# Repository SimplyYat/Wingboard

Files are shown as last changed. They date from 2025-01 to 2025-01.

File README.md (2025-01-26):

# Wingboard

> [!IMPORTANT]
> This is a work in progress.

A unibody ergonomic keyboard developed using [Ergogen](https://github.com/ergogen/ergogen) based on the [Absolem keyboard design](https://zealot.hu/absolem/).

## Row Column Matrix
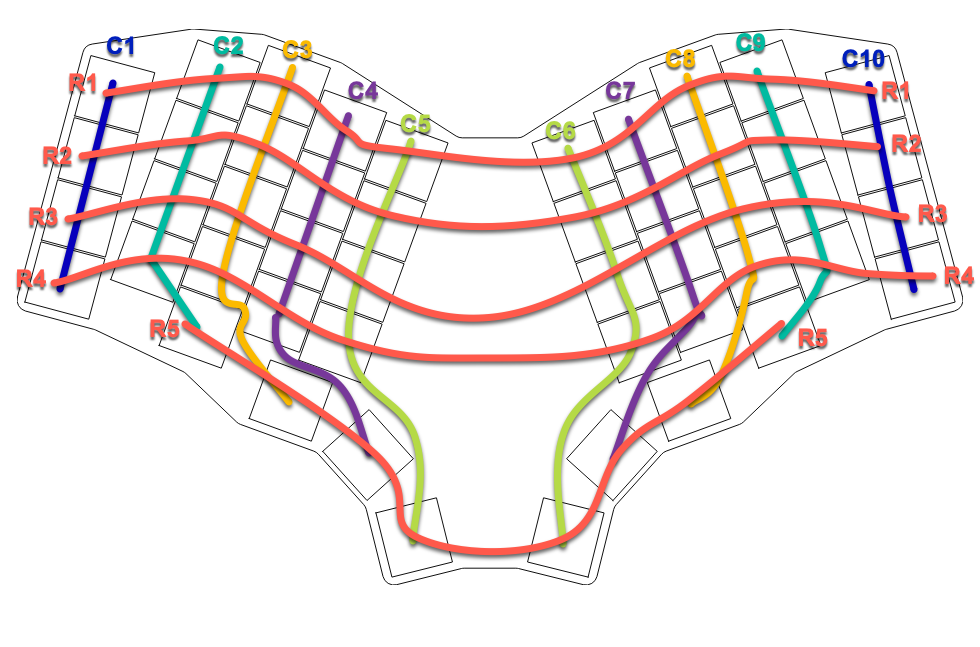
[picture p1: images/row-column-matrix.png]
Rows and Columns matrix


## Components needed

Component | Type (THT, SMD, or No Solder) | Link | Quantity | LCSC Part Number (for SMT Assembly through JLCPCB)
---------|---------|----------|---------|---------
 Diode SOD-123/323 (1N4148/W) | SMD | [AliExpress](https://www.aliexpress.com/item/1005003194674618.html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) | 48 | [C81598](https://jlcpcb.com/partdetail/st_semtech-1N4148W/C81598)
 Kailh Low Profile Hot Swap Switches | SMD | [AliExpress](https://www.aliexpress.com/item/1005003575767699.html?spm=a2g0o.detail.0.0.52b8WBreWBreoo&mp=1) | 48 | [C5333465](https://jlcpcb.com/partdetail/Kailh-CPG135001S30/C5333465)
 Choc V2 Key Switches | No Solder | [Deep Sea Silent Switches](https://www.aliexpress.com/item/1005008113631450.html?spm=a2g0o.detail.0.0.52b8WBreWBreoo&mp=1), [Choose from here](https://www.aliexpress.com/item/1005006626760418.html?spm=a2g0o.detail.0.0.52b8WBreWBreoo&mp=1), or find your own | 48 | Manual install
 Choc V2 Key Caps | No Solder | 48 | Manual install
 Supermini NRF52840 MCU | THT | [AliExpress](https://www.aliexpress.com/item/1005001621678794.html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) | 1 | Manual install
 Nice!View Display | THT | [Nice!View](https://nicekeyboards.com/nice-view) | 1 | Manual install
 EC11/12 Rotary Encoder | THT | [AliExpress](https://www.aliexpress.com/item/1005007644083514.html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) | 1 | Manual install
 Knob for the rotary encoder shaft | No Solder | [AliExpress](https://www.aliexpress.com/item/1005004171280417.html?spm=a2g0o.detail.0.0.52b8WBreWBreoo&mp=1) | 1 | Manual install
 Side Push Reset Switch (EVQPUC02K) | SMD | [AliExpress](https://www.aliexpress.com/item/1005002845025014.html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) | 1 | [C79174](https://jlcpcb.com/partdetail/Panasonic-EVQPUC02K/C79174)
 Power Switch | SMD | TBD | 1 | Manual install
 JST PH 2.0mm 2-Pin Connector for Battery | SMD | [AliExpress (Horizontal ones)](https://www.aliexpress.com/item/1005005716487667.html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) | 1 | [C7527581](https://jlcpcb.com/partdetail/Lian_XinTechnology-XDWF_092002P/C7527581)

## How to build
1. Order the PCB from the `pcb/production` folder through your preferred PCB fabrication service like JLCPCB, PCBWay, etc.
2. If you're ordering through JLCPCB, you can optionally use their SMT Assembly service to solder some components for you, the LCSC parts number are already added to the PCB, use the `pcb/production/bom.csv` and `pcb/production/positions.csv` as the BOM and Pick and Place files, respectively. Currently, the PCB includes LCSC part numbers for the bottom side only, for these parts (check the LCSC column above for links):
   1. 1N4148W SMD Diodes
   2. Kailh Low Profile Hot Swap Switches (they didn't have these in stock, so I couldn't order them, but they're there for when they have stock)
   3. Side Push Reset Switch (EVQPUC02K)
   4. JST PH 2.0mm 2-Pin Connector for Battery
   5. SMD Slider Power Switch
3. Source the rest of the components from your preferred suppliers and get to Soldering.
4. I'm still working on building a top case for this keyboard, so stay tuned for updates.

## Pending Items
1. [ ] Add top case with cutouts for:
    1. [ ] Nice view display
    2. [ ] Reset switch (TL3342 low profile - 2mm+ hole at the top)
    3. [ ] EC11/12 rotary encoder
    4. [ ] Power switch
    5. [ ] USB-C port
    6. [ ] Screw holes
 2. [ ] Adjust bottom case height to allow battery and PCB clearance
 3. [x] Route PCB
 4. [x] Add Wings image to PCB (Nice to have) 

## Notes
1. To get this repo, including the submodule `kb_ergogen_helper`, run the following command:
```bash
git clone --recursive <URL of this repo>
```
2. Since the addition of the `Makefile`, the following command can be used to build the output, convert the *.jscad* files to *.stl* in the `output/cases` path, and update traces on the PCB from last changes:
```bash
make build
```
3. If the make command above doesn't work, then build the output and convert the *.jscad* files to *.stl* in the `output/cases` path, run the following command from the current directory:
```bash
ergogen . && for f in output/cases/*.jscad; do npx @jscad/cli@1 $f -of stla -o ${f%.*}.stl; done
```
OR
```powershell
foreach ($file in Get-Item .\output\cases\*.jscad) {
   $basefilename=[System.IO.Path]::GetFileNameWithoutExtension($file.Name)
   npx @jscad/cli@1 $file -of stla -o ./output/cases/$basefilename.stl
}
```

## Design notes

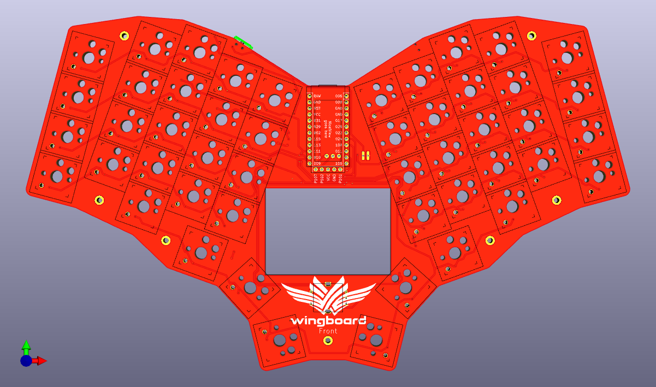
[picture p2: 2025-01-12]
pcb/Wingboard PCB Front.png

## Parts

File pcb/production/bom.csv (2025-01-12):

Designator | Footprint | Quantity | Value | LCSC Part #
D1, D10, D11, D12, D13, D14, D15, D16, D17, D18, D19, D2, D20, D21, D22, D23, D24, D25, D26, D27, D28, D29, D3, D30, D31, D32, D33, D34, D35, D36, D37, D38, D39, D4, D40, D41, D42, D43, D44, D45, D46, D47, D48, D5, D6, D7, D8, D9 | diode_tht_sod123 | 48 |  | C81598
H1, H2, H3, H4, H5, H6, H7 | mounting_hole_plated | 7
JST_BAT1 | JST_PH_S2B-PH-SM4-TB_1x02-1MP_P2.00mm_Horizontal | 1 | JST_PH_S2B-PH-SM4-TB_1x02-1MP_P2.00mm_Horizontal | C7527581
PWR1 | SW_SPDT_PCM12 | 1 | SW_SPDT_PCM12 | C128955
RE1 | rotary_encoder_ec11_ec12 | 1
RST1 | Panasonic_EVQPUL_EVQPUC | 1 | Panasonic_EVQPUL_EVQPUC | C79174
S1, S10, S11, S12, S13, S14, S15, S16, S17, S18, S19, S2, S20, S21, S22, S23, S24, S25, S26, S27, S28, S29, S3, S30, S31, S32, S33, S34, S35, S36, S37, S38, S39, S4, S40, S41, S42, S43, S44, S45, S46, S47, S48, S5, S6, S7, S8, S9 | switch_choc_v1_v2 | 48 |  | C5333465

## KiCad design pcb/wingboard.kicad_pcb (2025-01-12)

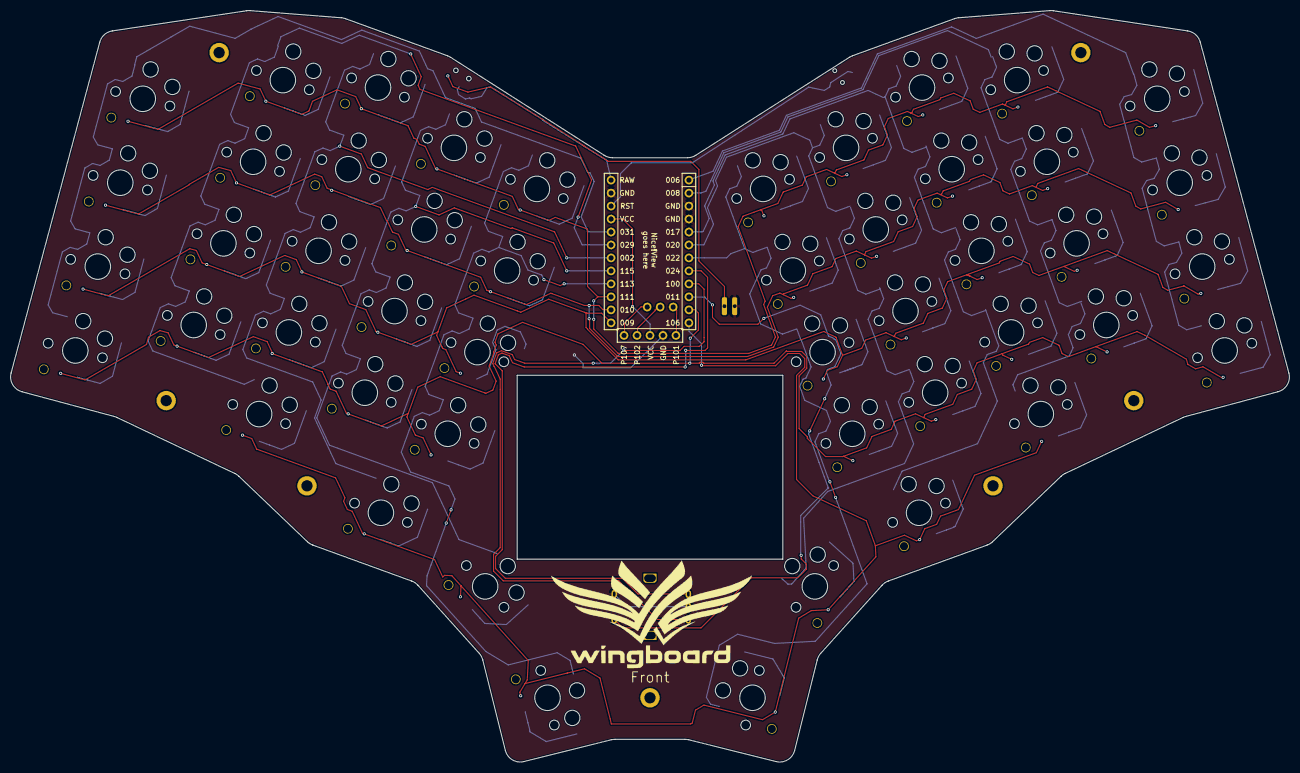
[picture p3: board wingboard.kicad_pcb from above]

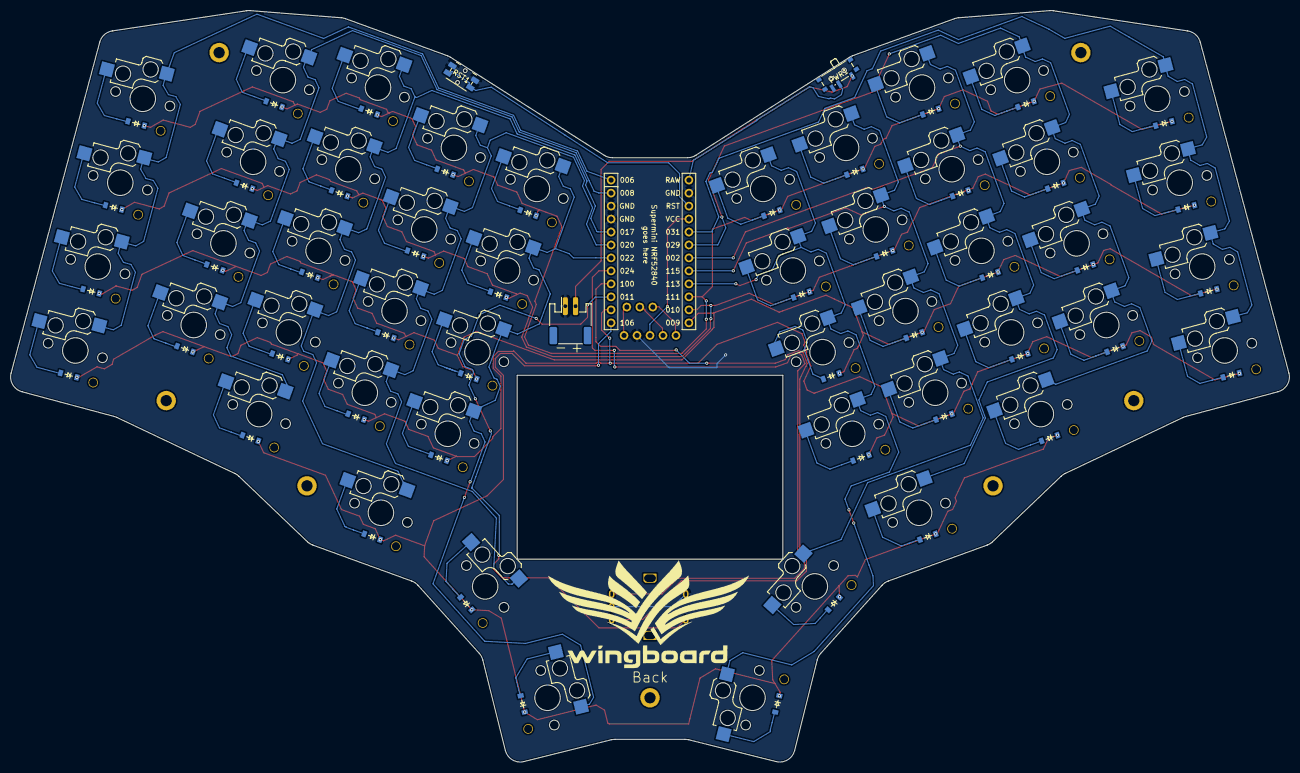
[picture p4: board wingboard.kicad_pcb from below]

Board: 2 copper layers, 250.3 x 147.1 mm, 109 parts (99 on the bottom side), 74 nets.

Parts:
D1, D2, D3, D4, D5, D6, D7, D8, D9, D10, D11, D12, D13, D14, D15, D16, D17, D18, D19, D20, D21, D22, D23, D24, D25, D26, D27, D28, D29, D30, D31, D32, D33, D34, D35, D36, D37, D38, D39, D40, D41, D42, D43, D44, D45, D46, D47, D48: diode_tht_sod123
DISP1: display_nice_view
H1, H2, H3, H4, H5, H6, H7: mounting_hole_plated
JST_BAT1: JST_PH_S2B-PH-SM4-TB_1x02-1MP_P2.00mm_Horizontal
MCU1: mcu_supermini_nrf52840
PWR1: SW_SPDT_PCM12
RE1: rotary_encoder_ec11_ec12
RST1: Panasonic_EVQPUL_EVQPUC
S1, S2, S3, S4, S5, S6, S7, S8, S9, S10, S11, S12, S13, S14, S15, S16, S17, S18, S19, S20, S21, S22, S23, S24, S25, S26, S27, S28, S29, S30, S31, S32, S33, S34, S35, S36, S37, S38, S39, S40, S41, S42, S43, S44, S45, S46, S47, S48: switch_choc_v1_v2

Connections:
BAT_P: JST_BAT1.2, PWR1.1
GND: DISP1.4, JST_BAT1.1, MCU1.3, MCU1.4, MCU1.23, RE1.B, RE1.S2, RST1.1
P002: MCU1.18, S10.1, S11.1, S12.1, S13.1, S22.1
P006: MCU1.1, S25.1, S26.1, S27.1, S28.1
P008: MCU1.2, S29.1, S30.1, S31.1, S32.1, S33.1
P009: D2.1, D6.1, D11.1, D15.1, D19.1, D26.1, D30.1, D35.1, D39.1, D43.1, MCU1.13
P010: D3.1, D7.1, D12.1, D16.1, D20.1, D27.1, D31.1, D36.1, D40.1, D44.1, MCU1.14
P011: MCU1.10, RE1.S1
P017: MCU1.5, S34.1, S35.1, S36.1, S37.1, S46.1
P020: MCU1.6, S38.1, S39.1, S40.1, S41.1, S47.1
P022: MCU1.7, S42.1, S43.1, S44.1, S45.1, S48.1
P024: MCU1.8, RE1.A
P029: MCU1.19, S5.1, S6.1, S7.1, S8.1, S9.1
P031: MCU1.20, S1.1, S2.1, S3.1, S4.1
P100: MCU1.9, RE1.C
P101: DISP1.5, MCU1.25
P102: DISP1.2, MCU1.26
P104: D1.1, D5.1, D10.1, D14.1, D18.1, D25.1, D29.1, D34.1, D38.1, D42.1, MCU1.11
P106: D9.1, D22.1, D23.1, D24.1, D33.1, D46.1, D47.1, D48.1, MCU1.12
P107: DISP1.1, MCU1.27
P111: D4.1, D8.1, D13.1, D17.1, D21.1, D28.1, D32.1, D37.1, D41.1, D45.1, MCU1.15
P113: MCU1.16, S18.1, S19.1, S20.1, S21.1, S24.1
P115: MCU1.17, S14.1, S15.1, S16.1, S17.1, S23.1
RAW: MCU1.24, PWR1.2
RST: MCU1.22, RST1.2
VCC: DISP1.3, MCU1.21
far_thumb: D24.2, S24.2
home_thumb: D23.2, S23.2
index_r1: D17.2, S17.2
index_r2: D16.2, S16.2
index_r3: D15.2, S15.2
index_r4: D14.2, S14.2
inner_r1: D21.2, S21.2
inner_r2: D20.2, S20.2
inner_r3: D19.2, S19.2
inner_r4: D18.2, S18.2
middle_r1: D13.2, S13.2
middle_r2: D12.2, S12.2
middle_r3: D11.2, S11.2
middle_r4: D10.2, S10.2
middle_r5: D9.2, S9.2
mirror_far_thumb: D48.2, S48.2
mirror_home_thumb: D47.2, S47.2
mirror_index_r1: D41.2, S41.2
mirror_index_r2: D40.2, S40.2
mirror_index_r3: D39.2, S39.2
mirror_index_r4: D38.2, S38.2
mirror_inner_r1: D45.2, S45.2
mirror_inner_r2: D44.2, S44.2
mirror_inner_r3: D43.2, S43.2
mirror_inner_r4: D42.2, S42.2
mirror_middle_r1: D37.2, S37.2
mirror_middle_r2: D36.2, S36.2
mirror_middle_r3: D35.2, S35.2
mirror_middle_r4: D34.2, S34.2
mirror_middle_r5: D33.2, S33.2
mirror_near_thumb: D46.2, S46.2
mirror_pinky_r1: D28.2, S28.2
mirror_pinky_r2: D27.2, S27.2
mirror_pinky_r3: D26.2, S26.2
mirror_pinky_r4: D25.2, S25.2
mirror_ring_r1: D32.2, S32.2
mirror_ring_r2: D31.2, S31.2
mirror_ring_r3: D30.2, S30.2
mirror_ring_r4: D29.2, S29.2
near_thumb: D22.2, S22.2
pinky_r1: D4.2, S4.2
pinky_r2: D3.2, S3.2
pinky_r3: D2.2, S2.2
pinky_r4: D1.2, S1.2
ring_r1: D8.2, S8.2
ring_r2: D7.2, S7.2
ring_r3: D6.2, S6.2
ring_r4: D5.2, S5.2

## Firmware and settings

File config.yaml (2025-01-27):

meta:
  engine: 4.1.0 # Min Ergogen version for KiCad 8 footprints
  version: 0.1
  author: "SimplyYat"
units:
  # Key Size Variables (cx and cy are choc sizes, replace with u for mx)
  kx: cx
  ky: cy
  # Switch size variables
  sx: 14
  sy: 14
  # Padding Variables
  px: kx + 4
  py: ky + 4
  # Double Padding Variables
  dpx: kx + 8
  dpy: ky + 8
  # Half values
  halfX: (px / 2)
  halfY: (py / 2)
  # Double half values
  dHalfX: (dpx / 2)
  dHalfY: (dpy / 2)
  # Defaults to M2 Screw Inserts
  screwSize: 1.5
  standoffSize: 2.5
  # PCB assembly component dimensions
  pcbThickness: 1.6
  switchInnerHeight: 2.2
  millMaxConnectorHeight: 10
  millMaxConnectorThickness: 3
  millMaxSolderHeight: 1.5
  # Rotary encoder cutout width and height
  # 15mm semicircle handle EC11 from here: https://www.aliexpress.com/item/1005007644083514.html?spm=a2g0o.order_list.order_list_main.34.75071802s8Sylp
  encoderBaseX: 14.7
  encoderBaseY: 12
  encoderShaftRadius: 3
  encoderShaftHeight: 15
  encoderBaseHeight: 6.5
  # Nice!View Sizes
  displaySizeX: 12.8
  displaySizeY: 27.3
  displayBezel: 1
  niceViewConnectorHeight: 7.5
  niceViewConnectorY: 4.6
  niceViewBaseX: 14
  niceViewBaseY: 36
  niceViewModuleThickness: 3
  # Battery Cutout Size
  batteryCutoutX: 36
  batteryCutoutY: 52
  # MCU Size
  mcuSizeX: 18
  mcuSizeY: 35
  mcuConnectorHeight: 9
  mcuPlusUSBThickness: 4
  mcuUSBWidth: 9
  mcuUSBOffset: 1
points:
  zones:
    matrix:
      key:
        padding: ky
        spread: kx
      anchor:
        rotate: 5
        # Fix placement on KiCAD sheet.
        shift: [100, -100]
      columns:
        pinky:
          rows.r5.skip: true
          key.column_net: P031
          key.mirror.column_net: P006
        ring:
          key.splay: -5
          key.origin: [-12, -19]
          key.stagger: 12
          rows.r5.skip: true
          key.column_net: P029
          key.mirror.column_net: P008
        middle:
          key.stagger: 5
          key.column_net: P002
          key.mirror.column_net: P017
          rows.r5.column_net: P029
          rows.r5.mirror.column_net: P008
        index:
          key.stagger: -6
          rows.r5.skip: true
          key.column_net: P115
          key.mirror.column_net: P020
        inner:
          key.stagger: -2
          rows.r5.skip: true
          key.column_net: P113
          key.mirror.column_net: P022
      rows:
        r5:
          row_net: P106
        r4:
          row_net: P104
        r3:
          row_net: P009
        r2:
          row_net: P010
        r1:
          row_net: P111
    thumbfan:
      key:
        padding: ky
        spread: kx
      anchor:
        ref: matrix_inner_r4
        shift: [-7, -19]
      columns:
        near:
          key.column_net: P002
          key.mirror.column_net: P017
        home:
          key.spread: 21.25
          key.splay: -28
          key.origin: [-11.75, -9]
          key.column_net: P115
          key.mirror.column_net: P020
        far:
          key.spread: 21.25
          key.splay: -28
          key.origin: [-9.5, -9]
          key.column_net: P113
          key.mirror.column_net: P022
      rows:
        thumb:
          row_net: P106
  rotate: -20
  mirror:
    ref: matrix_pinky_r5
    distance: 233.7529778
outlines:
  # Will be used for the mock PCB and the top case
  switchesOutline:
    - what: rectangle
      where: true
      bound: false
      size: [sx,sy]
  switchesTopLayers:
    - what: rectangle
      where: true
      bound: false
      size: [sx+1,sy+1]
  # Will be used for the PCB
  keys:
    - what: rectangle
      where: true
      bound: false
      size: [kx-0.5,ky-0.5]
  batteryOutline:
    - what: rectangle
      size: [batteryCutoutX,batteryCutoutY]
      where:
        ref.aggregate.parts: [matrix_inner_r2, mirror_matrix_inner_r2]
        shift: [0,-38.5]
        rotate: 90
  board:
    - what: polygon
      operation: stack
      fillet: 3
      points:
        - ref: matrix_pinky_r1
          shift: [-halfX,halfY]
        - ref: matrix_ring_r1
          shift: [-halfX,halfY]
        - ref: matrix_middle_r1
          shift: [-halfX,halfY]
        - ref: matrix_middle_r1
          shift: [halfX,halfY]
        - ref: matrix_inner_r1
          shift: [halfX,halfY]
        - ref: mirror_matrix_inner_r1
          shift: [halfX,halfY]
        - ref: mirror_matrix_middle_r1
          shift: [halfX,halfY]
        - ref: mirror_matrix_middle_r1
          shift: [-halfX,halfY]
        - ref: mirror_matrix_ring_r1
          shift: [-halfX,halfY]
        - ref: mirror_matrix_pinky_r1
          shift: [-halfX,halfY]
        - ref: mirror_matrix_pinky_r4
          shift: [-halfX,-halfY]
        - ref: mirror_matrix_pinky_r4
          shift: [halfX,-halfY]
        - ref: mirror_matrix_middle_r5
          shift: [0,-0.6py]
        - ref: mirror_thumbfan_near_thumb
          shift: [-halfX,-halfY]
        - ref: mirror_thumbfan_near_thumb
          shift: [halfX,-halfY]
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

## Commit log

2025-01-04 Added mounting holes and case
2025-01-04 Added mounting holes and cases
2025-01-05 Replaced choc with choc v2 footprints and updated readme
    [config.yaml]
2025-01-05 Added cutouts for top plate for nice view and reset button
2025-01-05 Replaced top reset switch with side switch and added submodule ergogen helper
    [config.yaml]
2025-01-05 Added Makefile to copy Kicad traces using kb_ergogen_helper
2025-01-05 Added cutout for rotary encoder
2025-01-06 Added Makefile and pcb folder
    [wingboard.kicad_pcb]
2025-01-06 Updated pcb
    [wingboard.kicad_pcb]
2025-01-07 More PCB routing changes
    [wingboard.kicad_pcb]
2025-01-08 PCB routing and added S1 and S2 connections for Rotary Encoder
2025-01-08 Updated the PCB
    [wingboard.kicad_pcb]
2025-01-09 Updated PCB and config
    [wingboard.kicad_pcb]
2025-01-10 Updated PCB, added new image footprint, and updated config
    [wingboard.kicad_pcb]
2025-01-10 New image footprint
2025-01-11 Added new footprints, updated PCB and config
    [wingboard.kicad_pcb]
2025-01-11 Updated footprints and config
2025-01-11 Added battery connector footprint
2025-01-12 Created Production PCB and updated Readme
    [bom.csv, designators.csv, positions.csv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]
2025-01-24 Added mocked assembled PCB
2025-01-24 Adding nice view assembly on pcb
